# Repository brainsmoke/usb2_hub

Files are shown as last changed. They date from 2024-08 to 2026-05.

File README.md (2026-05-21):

# A USB 2 Hub with per-port-power and MTT

Production files (JLCPCB): [gerbers](build/hub/gerbers_jlc.zip) [BOM](build/hub/bomfile_jlc.csv) [POS](build/hub/posfile_jlc.csv)

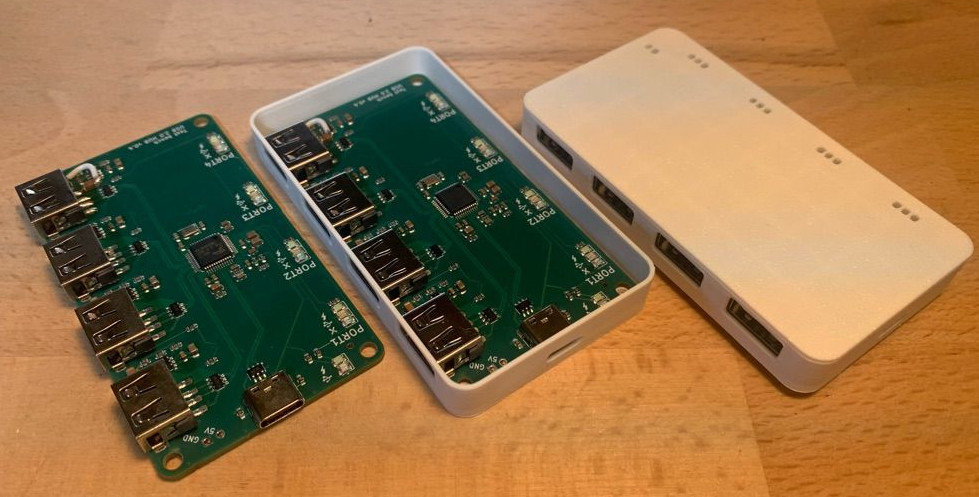
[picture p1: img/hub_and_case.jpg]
Image of a USB 2 Hub


This repository contains the [KiCad](https://www.kicad.org/) and [OpenScad](https://openscad.org/) files for a USB 2 Hub with per-port power and MTT.

The PCB design contains 4 USB-A ports and 1 USB-C port. The latter is used to connect the device to a computer.

If you want to switch power to ports you can use the provided [kernel interface](https://www.kernel.org/doc/html/latest/driver-api/usb/power-management.html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) or a userland utility such as [uhubctl](https://github.com/mvp/uhubctl).

## Case

OpenSCAD and STL files are available. These can be used to 3D print a case for the hub. The case can be assembled using countersunk M3 bolts with a maximum length of 8 mm.

* [Bottom](./build/hub/case_bottom.stl)
* [Top](./build/hub/case_top.stl)

## Revision errata:

### v0.7

* No known errata

### v0.4

* A capacitor and a USB-A connector are in the same place.

### v0.1

* instead of a 100k (busb <-> gnd) on r11, solder two 100k resistors from each of r11's pads
  to each of r10's pads (busb <-> 5v & gnd <-> vbusm)

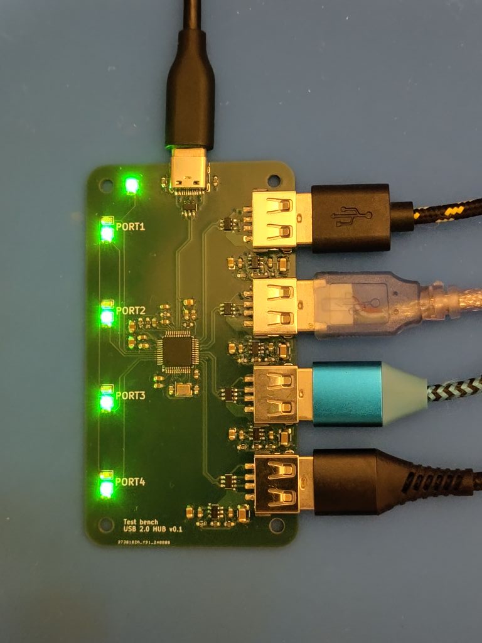
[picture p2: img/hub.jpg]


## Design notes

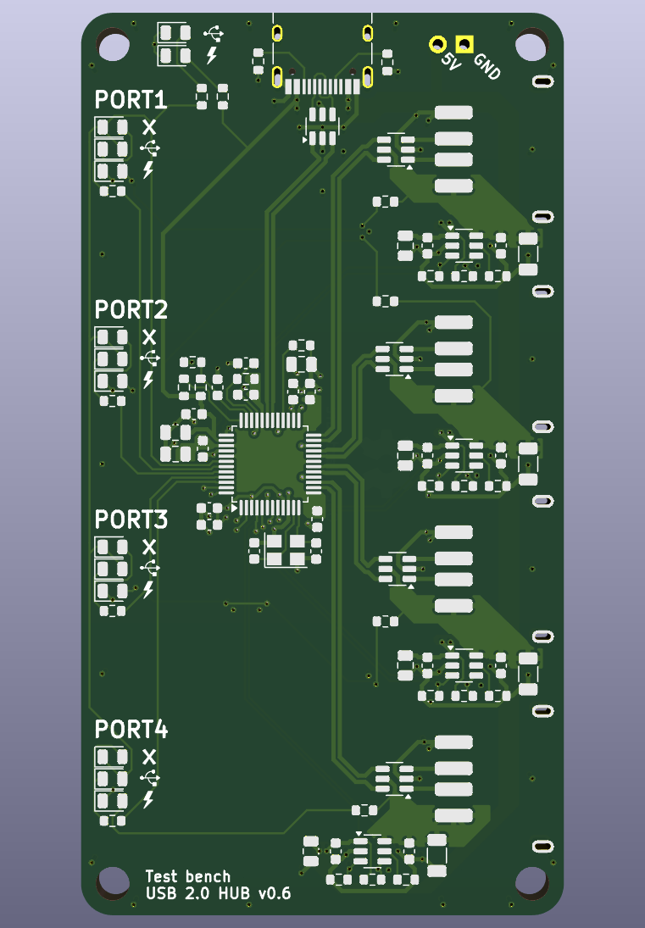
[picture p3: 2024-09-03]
img/v0.6.png

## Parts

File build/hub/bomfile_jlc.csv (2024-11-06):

Comment | Designator | Footprint | JLCPCB Part #
12pF | C1,C2 | Capacitor_SMD:C_0603_1608Metric | C38523
22uF | C13,C14,C15,C16 | Capacitor_SMD:C_1206_3216Metric | C12891
100nF | C3,C4,C9,C10,C11,C12,C17,C18,C19,C20,C21,C22,C23,C24,C27,C28,C29,C31 | Capacitor_SMD:C_0603_1608Metric | C14663
10uF | C5,C6,C7,C8,C25,C26,C30 | Capacitor_SMD:C_0805_2012Metric | C15850
LED | D1,D3,D5,D7 | LED_SMD:LED_0805_2012Metric | C965812
LED | D10,D11,D12,D13,D14 | LED_SMD:LED_0805_2012Metric | C965819
LED | D2,D4,D6,D8,D9 | LED_SMD:LED_0805_2012Metric | C2297
USB_C_Receptacle_USB2.0_16P | J5 | Library:USB_C_Receptacle_HRO_TYPE-C-31-M-12 | C165948
USB_A | J1,J2,J3,J4 | Library:SHOU HAN 10.0 QHHTZB6.3 | C668591
2K7 (1%) | R8 | Resistor_SMD:R_0603_1608Metric | C13167
47k | R11 | Resistor_SMD:R_0603_1608Metric | C25819
12k | R1,R3,R4,R7,R13,R14,R15,R17,R18,R19,R21,R22,R23,R24,R25,R26,R27,R28 | Resistor_SMD:R_0603_1608Metric | C22790
100k | R2,R9,R10,R12,R16,R20,R29 | Resistor_SMD:R_0603_1608Metric | C25803
510 | R30,R31,R32,R33 | Resistor_SMD:R_0603_1608Metric | C23193
5k1 | R5,R6 | Resistor_SMD:R_0603_1608Metric | C23186
FE1.1 | U1 | Package_QFP:LQFP-48_7x7mm_P0.5mm | C28958
AP22652AW6-7 | U2,U3,U4,U5 | Package_TO_SOT_SMD:SOT-23-6 | C5329413
USBLC6-2SC6 | U6,U7,U8,U9,U10 | Package_TO_SOT_SMD:SOT-23-6 | C7519
12MHz | Y1 | Crystal:Crystal_SMD_3225-4Pin_3.2x2.5mm | C50430

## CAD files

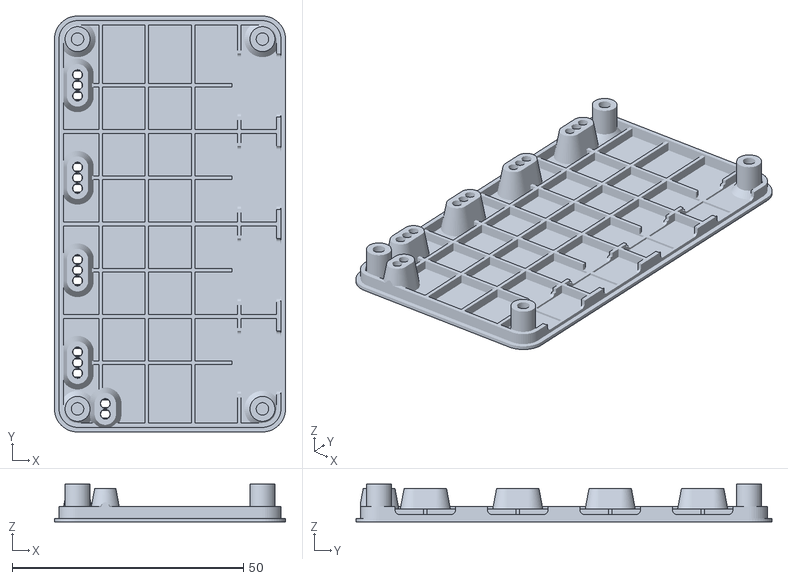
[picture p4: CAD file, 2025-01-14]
build/hub/case_top.stl
50.0 x 90.0 x 8.20

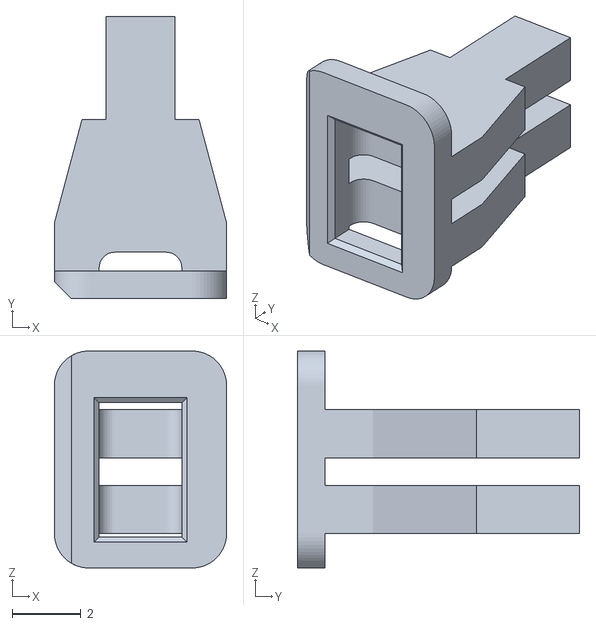
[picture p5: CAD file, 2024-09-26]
case/alternate_lightpipe_2led.stl
5.00 x 8.20 x 6.30

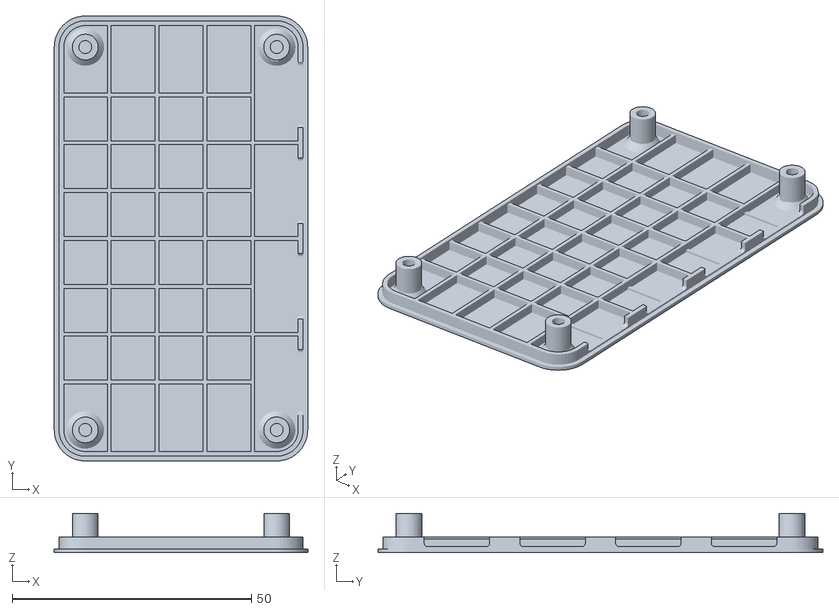
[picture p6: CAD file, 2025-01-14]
build/hub/case_v0.1_top.stl
53.0 x 93.0 x 8.20

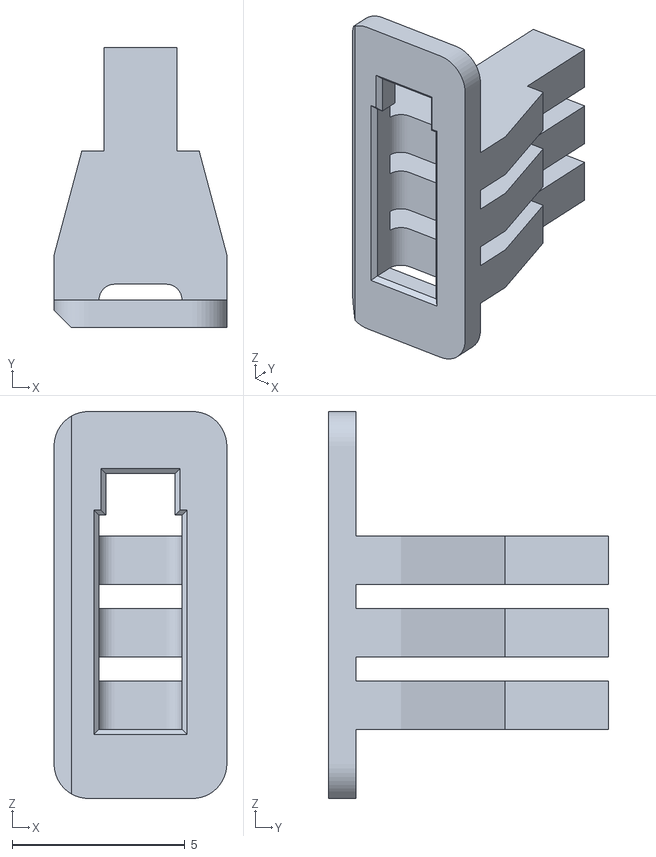
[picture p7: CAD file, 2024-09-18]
case/alternate_lightpipe_3led.stl
5.00 x 8.11 x 11.2

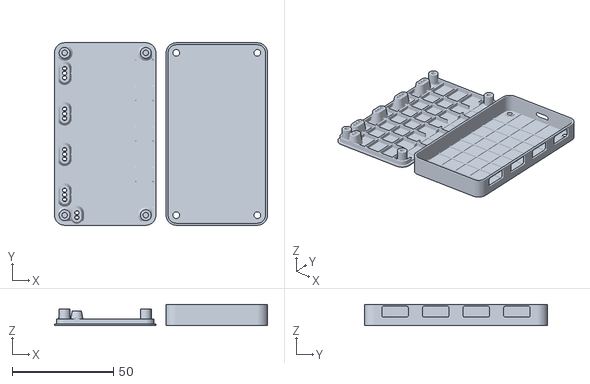
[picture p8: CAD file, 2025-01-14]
build/hub/case.stl
105.0 x 90.0 x 10.4

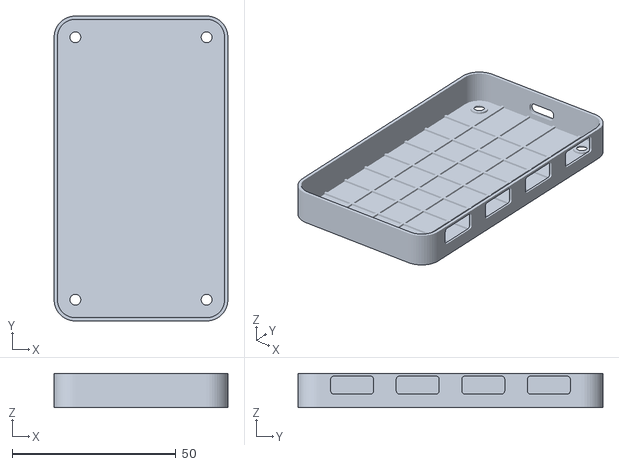
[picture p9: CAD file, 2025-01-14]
build/hub/case_v0.1_bottom.stl
53.0 x 93.0 x 10.4

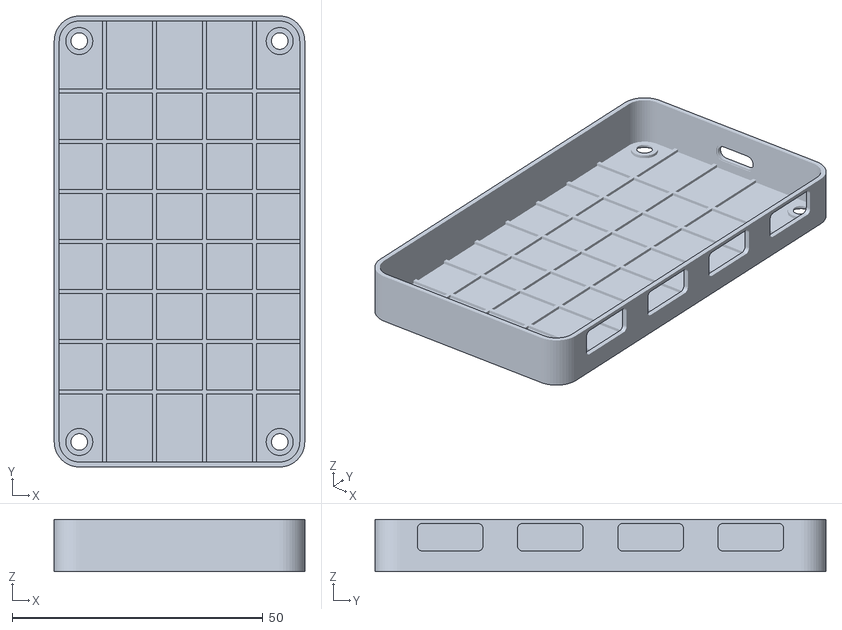
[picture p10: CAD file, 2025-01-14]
build/hub/case_bottom.stl
50.0 x 90.0 x 10.4

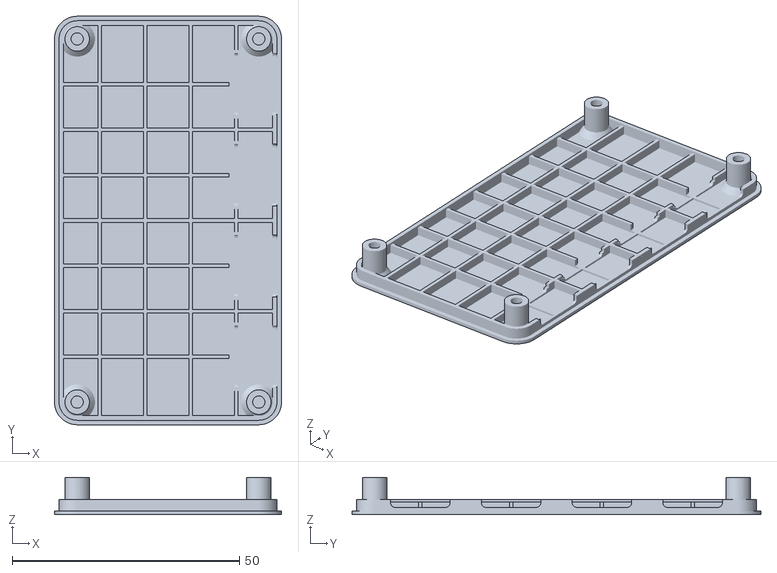
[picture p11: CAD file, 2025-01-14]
build/hub/case_nolightpipes_top.stl
50.0 x 90.0 x 8.20

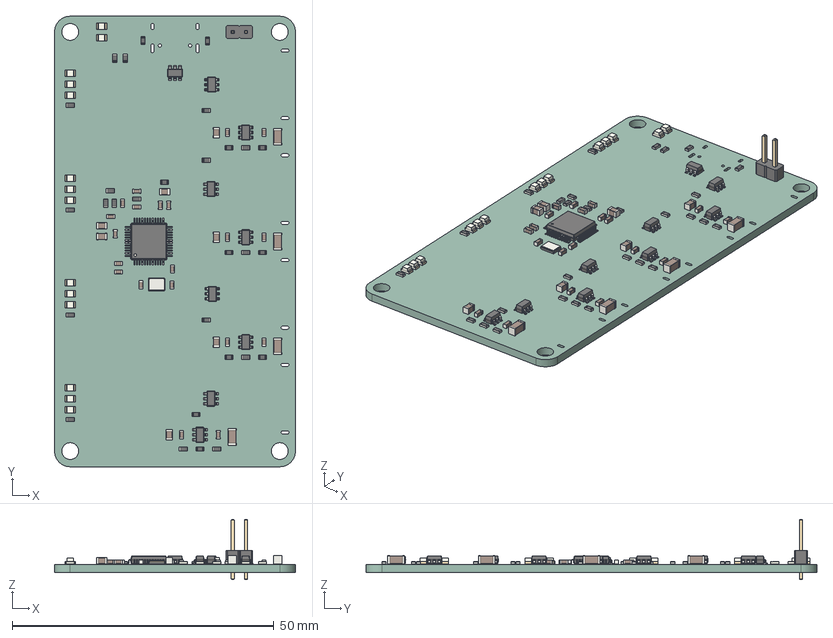
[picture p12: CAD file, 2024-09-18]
build/hub/project.step
46.0 x 86.0 x 11.5 mm
R_0603_1608Metric x 29
C_0603_1608Metric x 20
LED_0805_2012Metric x 14
SOT_23_6 x 9
C_0805_2012Metric x 7
LQFP_48_7x7mm_P05mm
C_1206_3216Metric x 4
PinHeader_1x02_P254mm_Vertical
Crystal_SMD_3225-4Pin_3.2x2.5mm
project_PCB

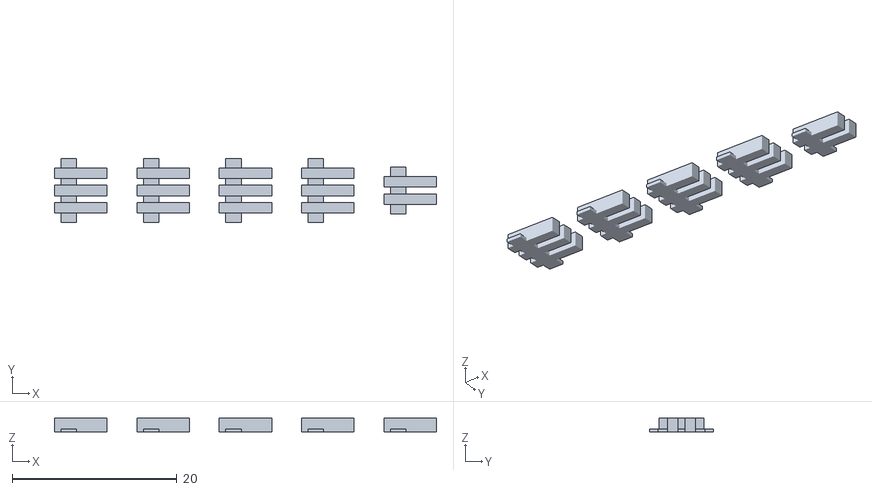
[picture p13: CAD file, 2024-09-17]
build/hub/lightpipe.stl
46.4 x 7.80 x 1.76

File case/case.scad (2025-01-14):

e=.001;
$fn=48;
padding=5;

use <usb.scad>

hole_dist_x = 40;
hole_dist_y = 80;
pcb_thickness = 1.6;
pcb_radius = 3;
inner_radius = 4;
wall_thickness = 1;
wall_height = 9.6;
thread = 3;
bottom_thickness = .8;
border_width = 1.;
top_thickness = .8;
top_edge_height = 2.5;
top_edge_width = 1.;
top_edge_margin = 0.;
top_grid_height = 2;
grid_width=.8;
leg_height = .6;
leg_radius = 2.7;

screw_hole_radius = 2.7;
screw_hole_radius_bottom = 3.9;
usb_c_board_offset = 3; // based on kicad position
screw_tension_gap = 0;

lightpipe_width = 2.5;
lightpipe_height = 1.6;
lightpipe_depth = .4;
lightpipe_guide_border_top = 1.2;
lightpipe_guide_border_bottom = 2.4;
lightpipe_diameter = 2.2;

led_pitch = 2.3; // 2.1 in reality, give the slicer a bit more space
led_x = hole_dist_x;

led_clearance = 1.;
outer_radius = inner_radius+wall_thickness;
screw_fit_radius = (thread*0.9)/2;

screw_loose_radius = (thread*1.1)/2;
screw_loose_radius_bottom = (thread*2)/2;
total_height = bottom_thickness+wall_height+top_thickness;
component_z = bottom_thickness+leg_height+pcb_thickness;

module notched_block(height, radius, notch_size)
{
	translate([notch_size-radius,-radius, 0])
		cube([hole_dist_x-2*(notch_size-radius), hole_dist_y+2*notch_size, height]);
	translate([-notch_size, notch_size-radius, 0])
		cube([hole_dist_x+2*notch_size, hole_dist_y-2*(notch_size-radius), height]);
}

module rounded_block(height, radius)
{
	notched_block(height, radius, radius);
	at_holes() cylinder(h=height, r=radius);
}


module preview()
{
	if ($preview) children();
}

module usb_c(margin=0)
{
	translate([0,-usb_c_board_offset,0]) 
	usb_c_type_c31_m12(margin) usb_c_plug(margin);
}

module usb_a(margin=0)
{
	usb_a_shou_han(margin) usb_a_plug(margin);
}

module usb_a_keepout()
{
	usb_a_shou_han(.25) usb_a_plug(.5);
}

module usb_c_keepout()
{
	usb_c(margin=.5);
}

module on_pcb()
{
	translate([0,0,component_z]) children();
}

module at_front()
{
	translate([hole_dist_x+pcb_radius,hole_dist_y/2,0]) rotate([0,0,-90])  children();
}

module at_top()
{
	translate([hole_dist_x/2,hole_dist_y+pcb_radius,0]) children();
}

module usb_a_locations()
{
	at_front() for (x=[-30,-10,10,30] ) translate([x, 0, 0]) children();
}

module led_locations()
{
	for (dy=[-30,-10,10,30] ) translate([0, hole_dist_y/2+dy, 0]) children();
}

module at_holes(x, y)
{
	for (x = [0, hole_dist_x])
		for (y = [0, hole_dist_y])
			translate([x,y,0])
				children();
}

module leg(h)
{
	translate([0,0,-e])
		cylinder(h=h+e, r=leg_radius);
}

module screw_hole(h)
{
	difference()
	{
union(){
	translate([0,0,-e])

		cylinder(h=h+e, r=leg_radius);

	translate([0,0,4/5*h])
		cylinder(h=h/5+e, r1=screw_hole_radius, r2=screw_hole_radius_bottom);
}
	translate([0,0,-e*2])
		cylinder(h=h+e*3, r=screw_fit_radius);
	}
}

module pcb()
{
	translate([0,0,bottom_thickness+leg_height])
		color("green")
			rounded_block(pcb_thickness, pcb_radius);
}

module h_grid(n, pitch, depth, w, h)
{
	translate([-w/2,-depth/2, 0])
		for (i=[0:n-1])
			translate([(i-(n-1)/2)*pitch,0,0])
				cube([w, depth, h]);
}

module grid(w, h, n_rows, row_pitch, n_cols, col_pitch, bar_w, bar_h)
{
	translate([hole_dist_x/2,hole_dist_y/2,0])
	{
		h_grid(n_rows, row_pitch, h, bar_w, bar_h);
		rotate([0,0,90])
		h_grid(n_cols, col_pitch, w, bar_w, bar_h);
	}
}


module case()
{

	difference()
	{
		union()
		{
			at_holes() translate([0, 0, bottom_thickness])leg(leg_height);
			difference()
			{
				rounded_block(bottom_thickness+wall_height, outer_radius);
				translate([0,0,bottom_thickness]) rounded_block(wall_height+e, inner_radius);
			}
		}
		union()
		{
			at_holes() translate([0,0,-e])
			{
		cylinder(h=leg_height+bottom_thickness+e-0.4, r2=screw_loose_radius, r1=screw_loose_radius_bottom);
		cylinder(h=leg_height+bottom_thickness+e*2, r=screw_loose_radius);
			}

			on_pcb()
			{
				at_top() usb_c_keepout();
				usb_a_locations() usb_a_keepout();
			}
		}
	}

	translate([0,0,bottom_thickness-e]) grid(hole_dist_x+(outer_radius-e)*2, hole_dist_y+(outer_radius-e)*2, 4, 10, 7, 10, grid_width, leg_height+e);
}

module light_pipe_keepout(n_leds)
{
	for (i=[0:n_leds-1])
	{
		dy = (i-(n_leds-1)/2)*led_pitch;
		w = lightpipe_width;
		h = lightpipe_height;
		z = total_height-lightpipe_depth;
		translate([-w/2, -h/2+dy, z-e]) 
			cube( [w,h,lightpipe_depth+e*2] );
	}

	for (i=[0:n_leds-1])
	{
	dy = (i-(n_leds-1)/2)*led_pitch;
	z = component_z + led_clearance;
    d = total_height-lightpipe_depth-z;
	r = lightpipe_diameter/2;

		translate([0, dy, z-e])
			cylinder(d, r); 
	}

}

module light_pipe(n_leds)
{
color("#f0f0f0")
{

	for (i=[0:n_leds-1])
	{
		dy = (i-(n_leds-1)/2)*led_pitch;
		z = component_z + led_clearance;
		translate([0,dy, z-e]) 
			cylinder(total_height-z-top_thickness, r=lightpipe_diameter/2);
	}
}
}

module light_pipe_guide(n_leds)
{
	hull()
	{
		for (i=[0:n_leds-1])
		{
			dy = (i-(n_leds-1)/2)*led_pitch;
			z = component_z + led_clearance;
			translate([0,dy, z-e]) 
				cylinder(total_height-z-top_thickness,
				         r1=lightpipe_diameter/2+lightpipe_guide_border_top,
				         r2=lightpipe_diameter/2+lightpipe_guide_border_bottom);
		}
	}
}

module leds_hub()
{
	translate([6,hole_dist_y,0])
		children();
}


module top()
{
	difference()
	{
		union()
		{
		translate([0,0,bottom_thickness+wall_height])
		{
			translate([0,0,-top_grid_height]) grid(hole_dist_x+(inner_radius+e)*2, hole_dist_y+(inner_radius+e)*2, 4, 10, 7, 10, grid_width, top_grid_height+e);

			rounded_block(top_thickness, outer_radius);
			difference()
			{
				translate([0,0,-top_edge_height])
				rounded_block(top_edge_height+e, inner_radius-top_edge_margin);
				translate([0,0,-top_edge_height-e])
				rounded_block(top_edge_height+2*e, inner_radius-top_edge_margin-top_edge_width);
			}
		}
			on_pcb() translate([0,0,screw_tension_gap]) at_holes() screw_hole(wall_height-pcb_thickness-leg_height+e);

			intersection()
			{
				union()
				{
					led_locations() light_pipe_guide(3);
					leds_hub() light_pipe_guide(2);
				}
				translate([0,0,-e])
				rounded_block(total_height+2*e, inner_radius-top_edge_margin-e);
			}
		}

		union()
		{
		on_pcb()
		{
			at_top() usb_c_keepout();
			usb_a_locations() usb_a_keepout();
		}
		led_locations() light_pipe_keepout(3);
		leds_hub() light_pipe_keepout(2);
		}
	}
}

module flip()
{
	translate([0,hole_dist_y,bottom_thickness+wall_height+top_thickness]) rotate([180,0,0]) children();
}

module next()
{
	translate([-hole_dist_x-2*outer_radius-padding,0 , 0]) children();
}

preview()
{
	pcb();
	on_pcb()
	{
		at_top() usb_c();
		usb_a_locations() usb_a();
	}
	flip()
	next()
	{
		led_locations() light_pipe(3);
		leds_hub() light_pipe(2);
	}
}

case();
next() 
flip()
top();

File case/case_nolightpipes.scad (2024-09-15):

include <case.scad>

module led_locations() { }
module leds_hub() { }

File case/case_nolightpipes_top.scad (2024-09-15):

use <case_nolightpipes.scad>

flip()
top();

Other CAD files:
case/case_v0.1_bottom.scad
case/alternate_lightpipe_3led.f3d
case/case_bottom.scad
case/case_top.scad
case/case_v0.1.scad
case/case_v0.1_top.scad
case/lightpipe.scad
case/lightpipe_test.scad
case/spacers.scad
case/spacers_alt.scad
case/usb.scad

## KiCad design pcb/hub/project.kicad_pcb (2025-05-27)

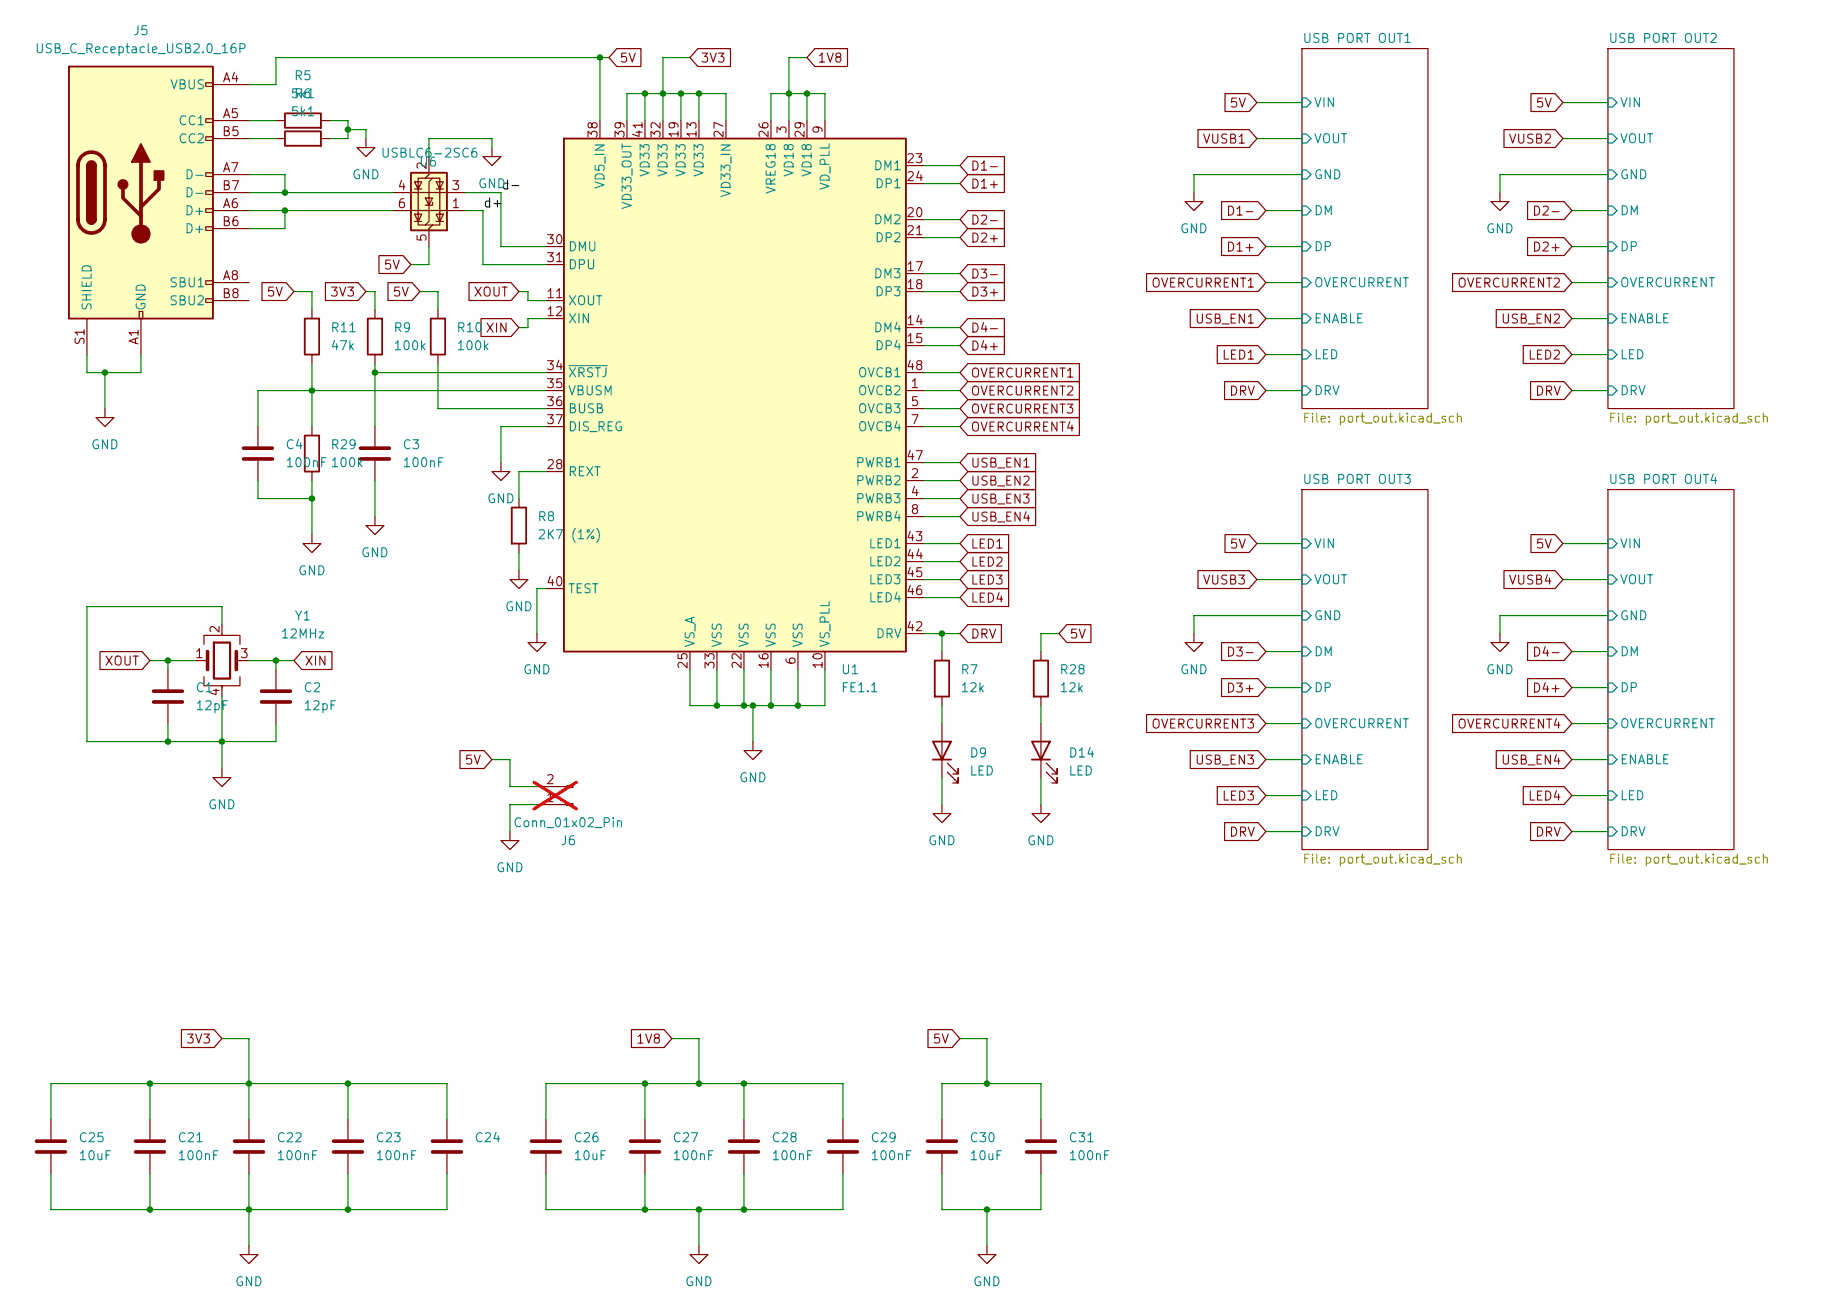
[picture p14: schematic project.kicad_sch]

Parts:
C1, C2: 12pF; C_0603_1608Metric; LCSC C38523
C3, C4, C21, C22, C23, C24, C27, C28, C29, C31: 100nF; C_0603_1608Metric; LCSC C14663
C25, C26, C30: 10uF; C_0805_2012Metric; LCSC C15850
D9: LED; LED_0805_2012Metric; LCSC C2297
D14: LED; LED_0805_2012Metric; LCSC C965819
J5: USB_C_Receptacle_USB2.0_16P; USB_C_Receptacle_HRO_TYPE-C-31-M-12; LCSC C165948
J6: Conn_01x02_Pin; PinHeader_1x02_P2.54mm_Vertical; not fitted
R5, R6: 5k1; R_0603_1608Metric; LCSC C23186
R7, R28: 12k; R_0603_1608Metric; LCSC C22790
R8: 2K7 (1%); R_0603_1608Metric; LCSC C13167
R9, R10, R29: 100k; R_0603_1608Metric; LCSC C25803
R11: 47k; R_0603_1608Metric; LCSC C25819
U1: FE1.1; LQFP-48_7x7mm_P0.5mm; LCSC C28958
U6: USBLC6-2SC6; SOT-23-6; LCSC C7519
Y1: 12MHz; Crystal_SMD_3225-4Pin_3.2x2.5mm; LCSC C50430

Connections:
1V8: C26.1, C27.1, C28.1, C29.1, U1.3 (VD18), U1.9 (VD_PLL), U1.26 (VREG18), U1.29 (VD18)
3V3: C21.1, C22.1, C23.1, C24.1, C25.1, R9.2, U1.13 (VD33), U1.19 (VD33), U1.27 (VD33_IN), U1.32 (VD33), U1.39 (VD33_OUT), U1.41 (VD33)
5V: C30.1, C31.1, J5.A4 (VBUS), J5.A9 (VBUS), J5.B4 (VBUS), J5.B9 (VBUS), J6.2, R10.2, R11.2, R28.1, U1.38 (VD5_IN), U6.5 (VBUS); also elsewhere on the board
/d+: U1.31 (DPU), U6.1 (I/O1)
/d-: U1.30 (DMU), U6.3 (I/O2)
D1+: U1.24 (DP1); also elsewhere on the board
D1-: U1.23 (DM1); also elsewhere on the board
D2+: U1.21 (DP2); also elsewhere on the board
D2-: U1.20 (DM2); also elsewhere on the board
D3+: U1.18 (DP3); also elsewhere on the board
D3-: U1.17 (DM3); also elsewhere on the board
D4+: U1.15 (DP4); also elsewhere on the board
D4-: U1.14 (DM4); also elsewhere on the board
DRV: R7.1, U1.42 (DRV); also elsewhere on the board
GND: C1.2, C2.2, C3.2, C4.2, C21.2, C22.2, C23.2, C24.2, C25.2, C26.2, C27.2, C28.2, C29.2, C30.2, C31.2, D9.1 (K), D14.1 (K), J5.A1 (GND), J5.A12 (GND), J5.B1 (GND), J5.B12 (GND), J5.S1 (SHIELD), J6.1, R5.2, R6.2, R8.2, R29.1, U1.6 (VSS), U1.10 (VS_PLL), U1.16 (VSS), U1.22 (VSS), U1.25 (VS_A), U1.33 (VSS), U1.37 (DIS_REG), U1.40 (TEST), U6.2 (GND), Y1.2, Y1.4; also elsewhere on the board
LED1: U1.43 (LED1); also elsewhere on the board
LED2: U1.44 (LED2); also elsewhere on the board
LED3: U1.45 (LED3); also elsewhere on the board
LED4: U1.46 (LED4); also elsewhere on the board
unnamed: D9.2 (A), R7.2
unnamed: D14.2 (A), R28.2
unnamed: J5.A5 (CC1), R5.1
unnamed: J5.B5 (CC2), R6.1
unnamed: J5.A6 (D+), J5.B6 (D+), U6.6 (I/O1)
unnamed: J5.A7 (D-), J5.B7 (D-), U6.4 (I/O2)
unnamed: R10.1, U1.36 (BUSB)
unnamed: R8.1, U1.28 (REXT)
unnamed: C4.1, R11.1, R29.2, U1.35 (VBUSM)
unnamed: C3.1, R9.1, U1.34 (~XRSTJ)
OVERCURRENT1: U1.48 (OVCB1); also elsewhere on the board
OVERCURRENT2: U1.1 (OVCB2); also elsewhere on the board
OVERCURRENT3: U1.5 (OVCB3); also elsewhere on the board
OVERCURRENT4: U1.7 (OVCB4); also elsewhere on the board
USB_EN1: U1.47 (PWRB1); also elsewhere on the board
USB_EN2: U1.2 (PWRB2); also elsewhere on the board
USB_EN3: U1.4 (PWRB3); also elsewhere on the board
USB_EN4: U1.8 (PWRB4); also elsewhere on the board
XIN: C2.1, U1.12 (XIN), Y1.3
XOUT: C1.1, U1.11 (XOUT), Y1.1

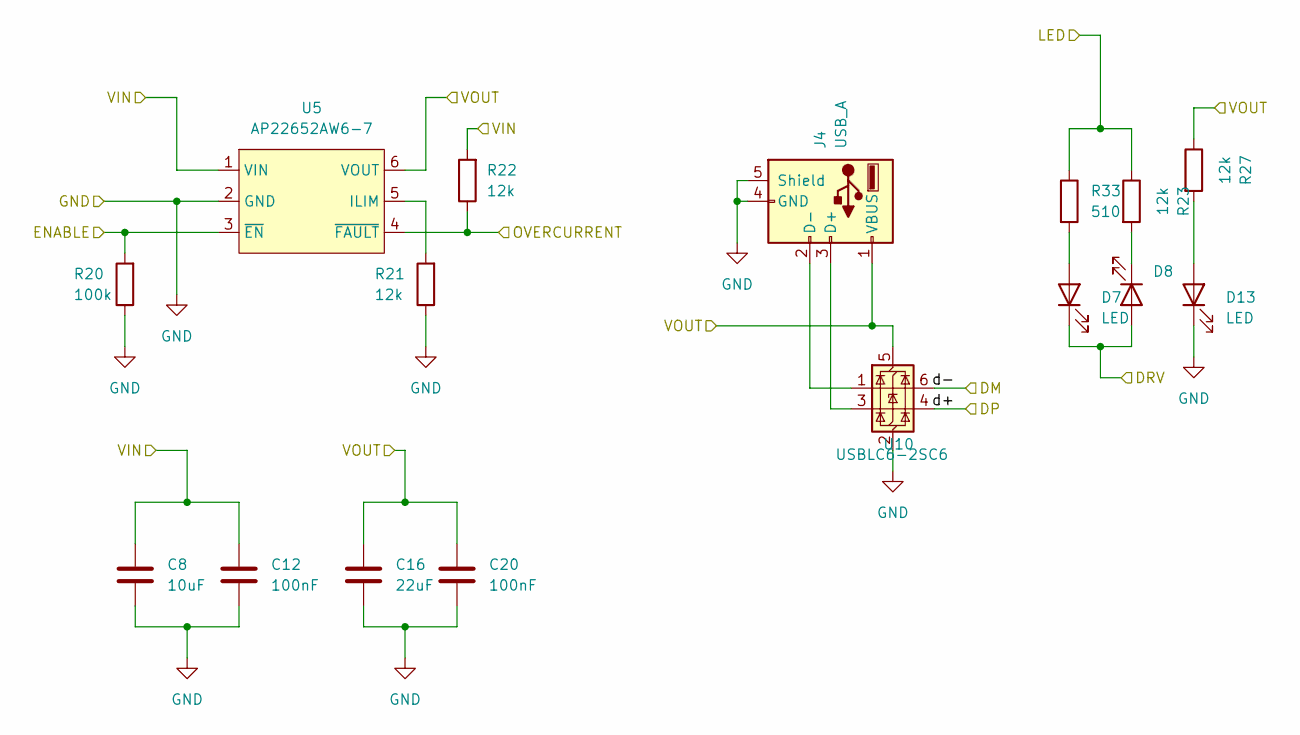
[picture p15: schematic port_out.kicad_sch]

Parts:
C8: 10uF; C_0805_2012Metric; LCSC C15850
C12, C20: 100nF; C_0603_1608Metric; LCSC C14663
C16: 22uF; C_1206_3216Metric; LCSC C12891
D7: LED; LED_0805_2012Metric; LCSC C965812
D8: LED; LED_0805_2012Metric; LCSC C2297
D13: LED; LED_0805_2012Metric; LCSC C965819
J4: USB_A; SHOU HAN 10.0 QHHTZB6.3; LCSC C668591
R20: 100k; R_0603_1608Metric; LCSC C25803
R21, R22, R23, R27: 12k; R_0603_1608Metric; LCSC C22790
R33: 510; R_0603_1608Metric; LCSC C23193
U5: AP22652AW6-7; SOT-23-6; LCSC C5329413
U10: USBLC6-2SC6; SOT-23-6; LCSC C7519

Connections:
5V: C8.1, C12.1, R22.2, U5.1 (VIN); also elsewhere on the board
D4+: U10.4 (I/O2); also elsewhere on the board
D4-: U10.6 (I/O1); also elsewhere on the board
DRV: D7.1 (K), D8.2 (A); also elsewhere on the board
GND: C8.2, C12.2, C16.2, C20.2, D13.1 (K), J4.4 (GND), J4.5 (Shield), R20.1, R21.1, U5.2 (GND), U10.2 (GND); also elsewhere on the board
LED4: R23.1, R33.1; also elsewhere on the board
unnamed: D7.2 (A), R33.2
unnamed: D8.1 (K), R23.2
unnamed: D13.2 (A), R27.2
unnamed: J4.3 (D+), U10.3 (I/O2)
unnamed: J4.2 (D-), U10.1 (I/O1)
unnamed: R21.2, U5.5 (ILIM)
OVERCURRENT4: R22.1, U5.4 (~FAULT); also elsewhere on the board
USB_EN4: R20.2, U5.3 (~EN); also elsewhere on the board
VUSB4: C16.1, C20.1, J4.1 (VBUS), R27.1, U5.6 (VOUT), U10.5 (VBUS)

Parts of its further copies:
C5, C6, C7: 10uF; C_0805_2012Metric; LCSC C15850
C9, C10, C11, C17, C18, C19: 100nF; C_0603_1608Metric; LCSC C14663
C13, C14, C15: 22uF; C_1206_3216Metric; LCSC C12891
D1, D3, D5: LED; LED_0805_2012Metric; LCSC C965812
D2, D4, D6: LED; LED_0805_2012Metric; LCSC C2297
D10, D11, D12: LED; LED_0805_2012Metric; LCSC C965819
J1, J2, J3: USB_A; SHOU HAN 10.0 QHHTZB6.3; LCSC C668591
R1, R3, R4, R13, R14, R15, R17, R18, R19, R24, R25, R26: 12k; R_0603_1608Metric; LCSC C22790
R2, R12, R16: 100k; R_0603_1608Metric; LCSC C25803
R30, R31, R32: 510; R_0603_1608Metric; LCSC C23193
U2, U3, U4: AP22652AW6-7; SOT-23-6; LCSC C5329413
U7, U8, U9: USBLC6-2SC6; SOT-23-6; LCSC C7519

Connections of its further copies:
5V: C5.1, C6.1, C7.1, C9.1, C10.1, C11.1, R4.2, R14.2, R18.2, U2.1 (VIN), U3.1 (VIN), U4.1 (VIN); also elsewhere on the board
D1+: U7.4 (I/O2); also elsewhere on the board
D1-: U7.6 (I/O1); also elsewhere on the board
D2+: U8.4 (I/O2); also elsewhere on the board
D2-: U8.6 (I/O1); also elsewhere on the board
D3+: U9.4 (I/O2); also elsewhere on the board
D3-: U9.6 (I/O1); also elsewhere on the board
DRV: D1.1 (K), D2.2 (A), D3.1 (K), D4.2 (A), D5.1 (K), D6.2 (A); also elsewhere on the board
GND: C5.2, C6.2, C7.2, C9.2, C10.2, C11.2, C13.2, C14.2, C15.2, C17.2, C18.2, C19.2, D10.1 (K), D11.1 (K), D12.1 (K), J1.4 (GND), J1.5 (Shield), J2.4 (GND), J2.5 (Shield), J3.4 (GND), J3.5 (Shield), R2.1, R3.1, R12.1, R13.1, R16.1, R17.1, U2.2 (GND), U3.2 (GND), U4.2 (GND), U7.2 (GND), U8.2 (GND), U9.2 (GND); also elsewhere on the board
LED1: R1.1, R30.1; also elsewhere on the board
LED2: R15.1, R31.1; also elsewhere on the board
LED3: R19.1, R32.1; also elsewhere on the board
unnamed: D1.2 (A), R30.2
unnamed: D2.1 (K), R1.2
unnamed: D3.2 (A), R31.2
unnamed: D4.1 (K), R15.2
unnamed: D5.2 (A), R32.2
unnamed: D6.1 (K), R19.2
unnamed: D10.2 (A), R24.2
unnamed: D11.2 (A), R25.2
unnamed: D12.2 (A), R26.2
unnamed: J1.3 (D+), U7.3 (I/O2)
unnamed: J1.2 (D-), U7.1 (I/O1)
unnamed: J2.3 (D+), U8.3 (I/O2)
unnamed: J2.2 (D-), U8.1 (I/O1)
unnamed: J3.3 (D+), U9.3 (I/O2)
unnamed: J3.2 (D-), U9.1 (I/O1)
unnamed: R13.2, U2.5 (ILIM)
unnamed: R3.2, U3.5 (ILIM)
unnamed: R17.2, U4.5 (ILIM)
OVERCURRENT1: R14.1, U2.4 (~FAULT); also elsewhere on the board
OVERCURRENT2: R4.1, U3.4 (~FAULT); also elsewhere on the board
OVERCURRENT3: R18.1, U4.4 (~FAULT); also elsewhere on the board
USB_EN1: R12.2, U2.3 (~EN); also elsewhere on the board
USB_EN2: R2.2, U3.3 (~EN); also elsewhere on the board
USB_EN3: R16.2, U4.3 (~EN); also elsewhere on the board
VUSB1: C13.1, C17.1, J1.1 (VBUS), R24.1, U2.6 (VOUT), U7.5 (VBUS)
VUSB2: C14.1, C18.1, J2.1 (VBUS), R25.1, U3.6 (VOUT), U8.5 (VBUS)
VUSB3: C15.1, C19.1, J3.1 (VBUS), R26.1, U4.6 (VOUT), U9.5 (VBUS)

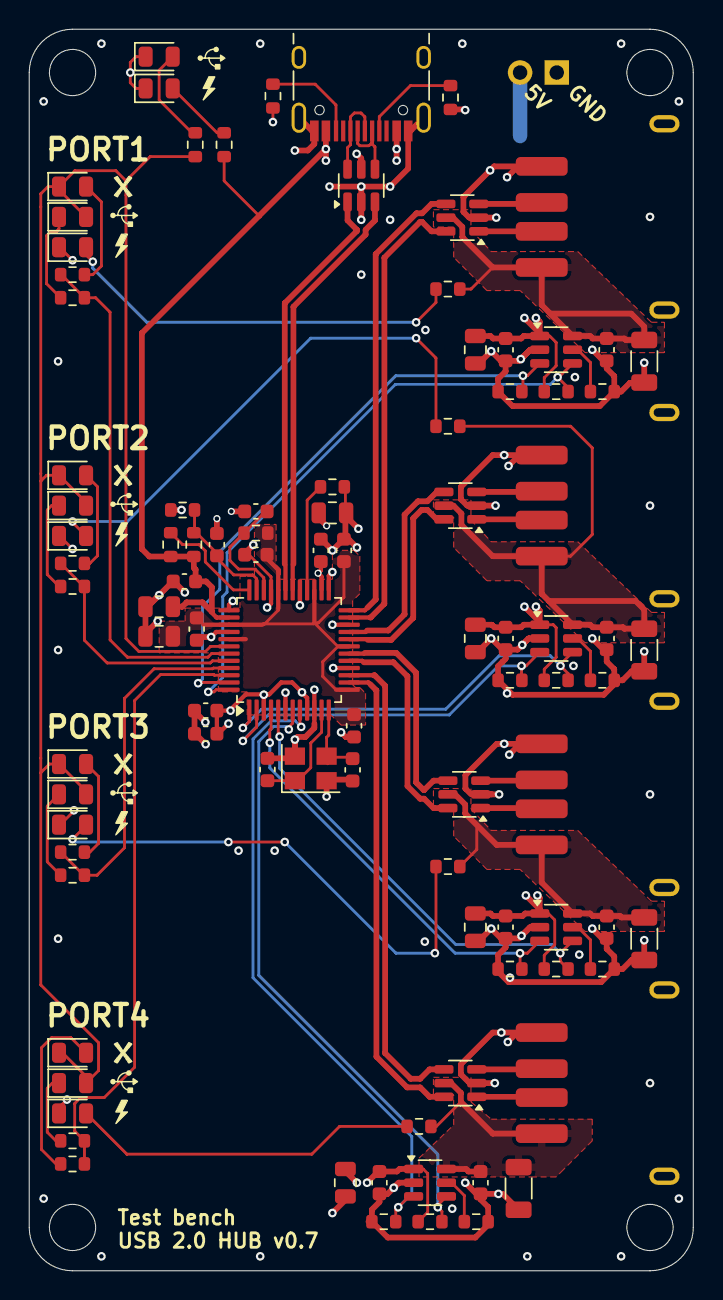
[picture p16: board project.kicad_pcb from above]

Board: 4 copper layers, 46.0 x 86.0 mm, 95 parts (0 on the bottom side), 67 nets.

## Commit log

2024-08-07 usb hub, untested
    [port_out.kicad_sch, project.kicad_pcb, project.kicad_sch]
2024-08-09 hopefully improve layout, still untested
    [project.kicad_pcb]
2024-08-21 use pull-up instead of pull-down on bus power input
    [project.kicad_pcb, project.kicad_sch]
2024-08-21 fix missing resistor
    [project.kicad_pcb, project.kicad_sch]
2024-08-22 add pcba files
    [bom.csv, port_out.kicad_sch, project.kicad_pcb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]
2024-08-22 add license
    [project.kicad_pcb]
2024-08-22 add OSHW logo
    [project.kicad_pcb]
2024-08-28 fix component overlap
    [project.kicad_pcb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]
2024-09-03 fix part number
    [bom.csv, port_out.kicad_sch, project.kicad_pcb]
2024-09-03 fix clearance issue
    [project.kicad_pcb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]
2024-09-04 add lasercut/3dprinted case & unfinished 3d print only design
    [case.scad, spacers.scad]
2024-09-07 minor clearance tweaks
    [project.kicad_pcb]
2024-09-07 update USB A footprint to use the same center location as JLCPCB uses
    [project.kicad_pcb]
2024-09-08 add jlc posfile converter
    [project.kicad_pcb, project.kicad_sch]
2024-09-09 add case, untested
    [case.scad, case_bottom.scad, case_bottom.stl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]
2024-09-09 add missing light pipe holes
    [case.scad, case_bottom.stl, case_top.stl]
2024-09-09 fix port orientations (oops)
    [case.scad, case_bottom.stl, case_top.stl]
2024-09-09 fix led positions
    [case.scad, case_top.stl]
2024-09-09 doc: mention case and bolts
2024-09-09 doc: image of case
    Add an image of the case and hub.
2024-09-10 raise connctors in model, hopefully improve light pipe
    [case.scad, case_bottom.stl, case_top.stl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]
2024-09-15 add cases without light pipes / for the first iteration of the PCB / tweak model to reduce stringing
    [case.scad, case_bottom.stl, case_nolightpipes.scad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]
2024-09-16 use makefile to generate kicad fabrication outputs
    [bomfile_jlc.csv, posfile_top_jlc.csv, project.kicad_pcb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]
2024-09-16 use a single Makefile
    [bomfile_jlc.csv, case_bottom.stl, case_top.stl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]
2024-09-16 move misplaced files
    [bomfile_jlc.csv, posfile_top_jlc.csv]
2024-09-16 remove old bomfile
    [bom.csv]
2024-09-17 add lightpipe model
    [case.scad, lightpipe.scad, lightpipe.stl]
2024-09-18 Check in PCB 3d model
    [project.step]
2024-09-18 Add alternate lightpipe for 3-led groups
    [alternate_lightpipe_3led.f3d, alternate_lightpipe_3led.stl]
2024-09-26 Add 2 led lightpipe
    [alternate_lightpipe_2led.stl]
2024-11-06 use separate resistor for red LED
    [bomfile_jlc.csv, port_out.kicad_sch, posfile_top_jlc.csv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]
2024-11-07 use new makefile
    [bomfile_jlc.csv, case.stl, case_bottom.stl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]
2024-11-09 add order number location
    [project.kicad_pcb]
2025-01-13 strengthen case, use filament as light pipes
    [case.scad, case.stl, case_bottom.stl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]
2025-01-13 fix drc warnings
    [project.kicad_pcb]
2025-01-13 add case.scad dependency to Makefile
2025-01-14 improve led pipes, fix extrusion interfering with case walls
    [case.scad, case.stl, case_bottom.stl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]
2025-01-15 ignore frequent library footprint mismatches due to software updates
    [project.kicad_pcb]
2025-01-20 retstore DRC warning as kicad no longer fails on mismatching comment fiels in 8.0.8
2025-01-20 fix silkscreen overlap
    [project.kicad_pcb]
2025-01-20 remove references again
    [project.kicad_pcb]
2025-03-01 recalculate usb trace impedance
    [project.kicad_pcb]
2025-05-04 Ignore lib footprint mismatches because they keep changing
2025-05-27 revert to old impedance matching, (matching) JLC economy stackup
    [project.kicad_pcb]

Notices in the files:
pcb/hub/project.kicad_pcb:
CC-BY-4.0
